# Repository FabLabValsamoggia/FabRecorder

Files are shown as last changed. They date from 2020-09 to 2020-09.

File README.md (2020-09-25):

# FabRecorder

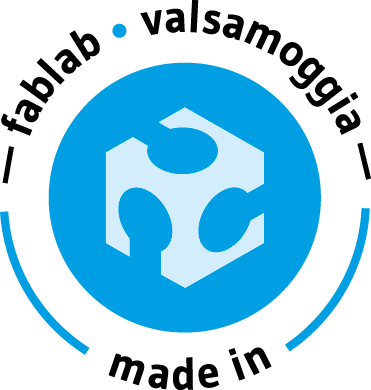
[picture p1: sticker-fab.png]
FabSticker


developed with ♥ by FabLab Valsamoggia

Based on [this awesome project](https://www.instructables.com/id/Make-Your-Own-Spy-Bug-Arduino-Voice-Recorder/).

**FabRecorder** is a little and adorable object, inspired by 007 gadget, that permits to record audio .wav format on SD card.

## Installation

Library requirements: [TMRpcm](https://github.com/TMRh20/TMRpcm). See code for other informations.

## Contributing

Pull requests are welcome. For major changes, please open an issue first to discuss what you would like to change.

Please make sure to update tests as appropriate.

## License

[MIT](https://choosealicense.com/licenses/mit/)

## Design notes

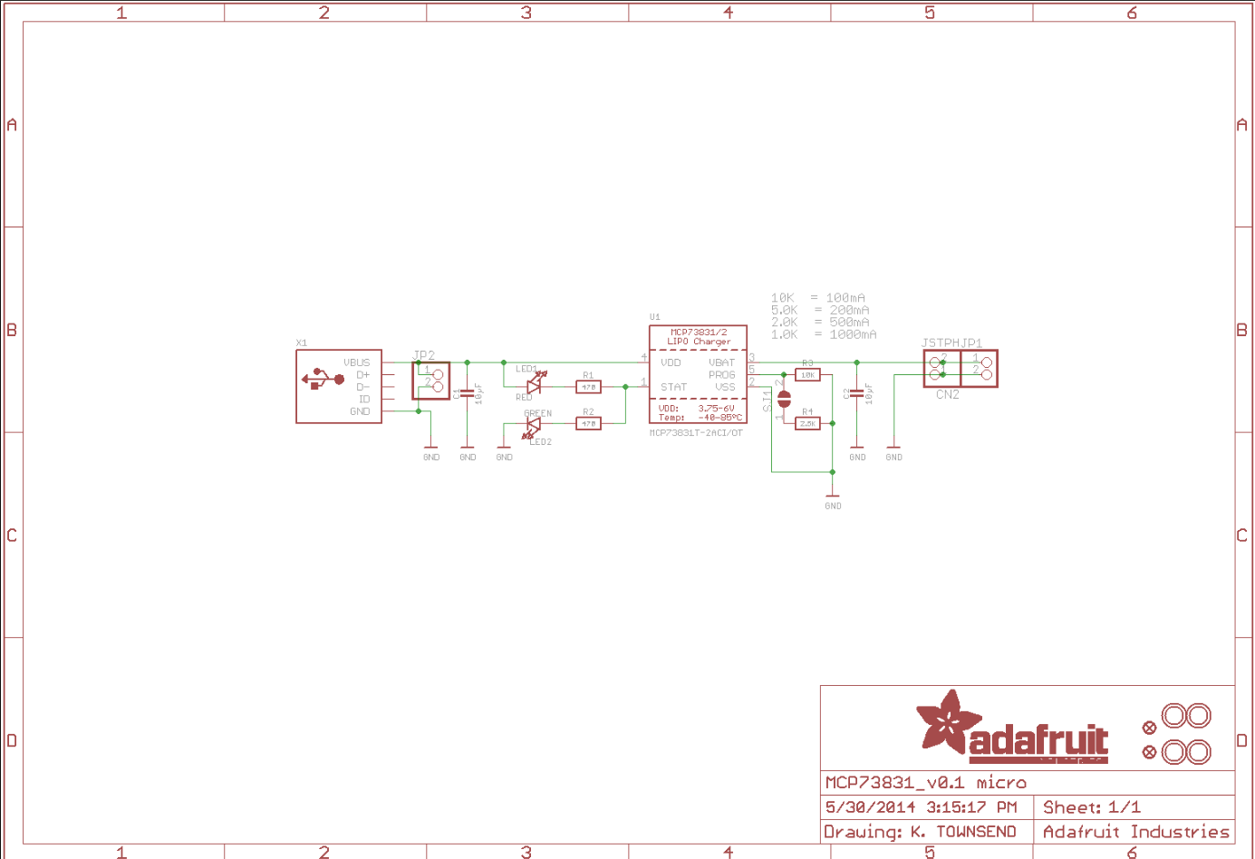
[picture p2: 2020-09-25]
doc/immagini/Annotazione 2020-04-22 233154.png

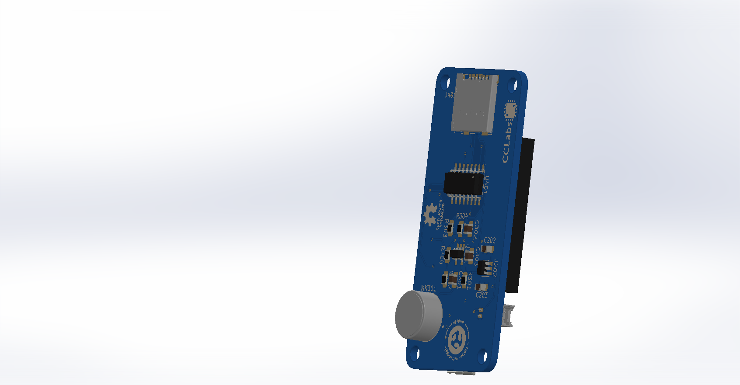
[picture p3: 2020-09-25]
doc/immagini/SPY_RECORDER-FBV010-Final2.PNG

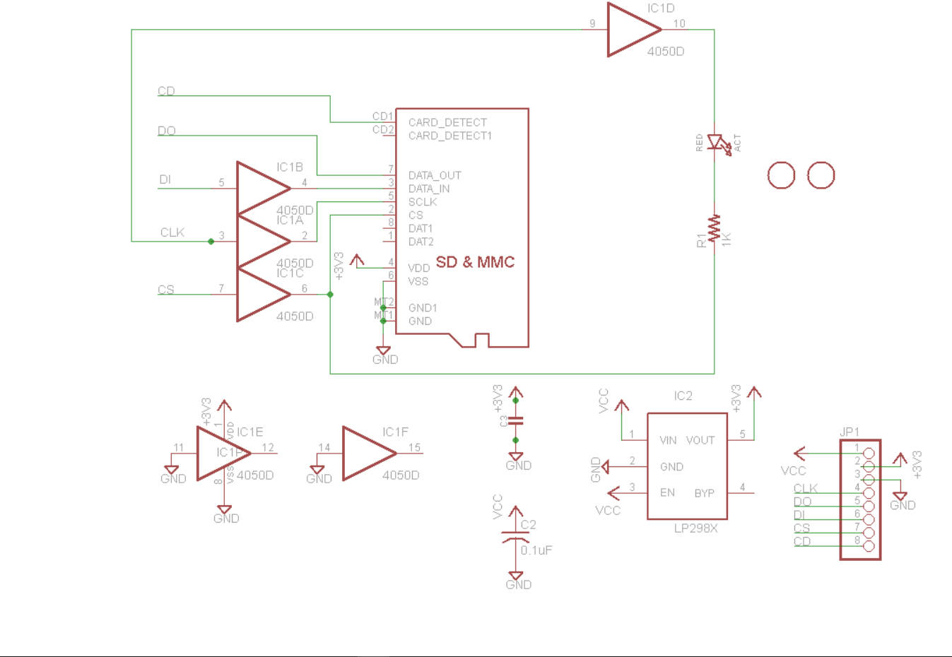
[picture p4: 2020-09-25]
doc/immagini/Annotazione 2020-04-22 232143.png

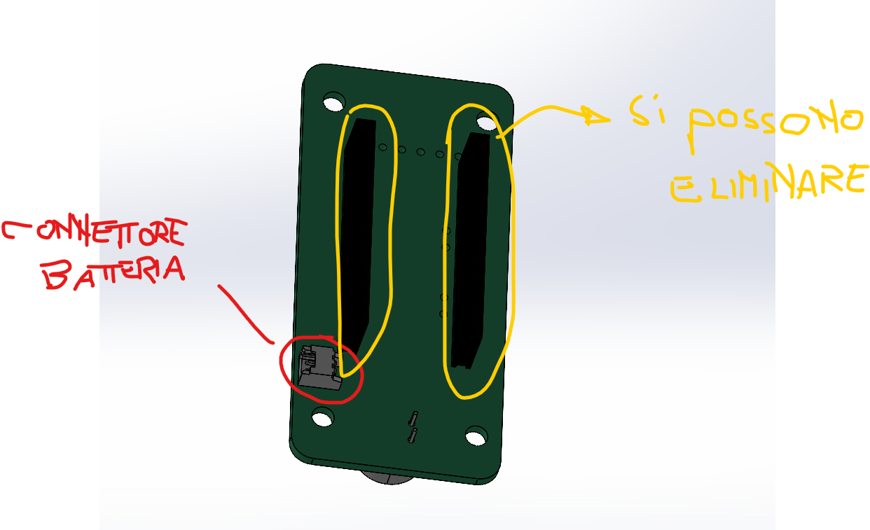
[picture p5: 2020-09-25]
doc/immagini/Annotazione 2020-04-23 194736.png

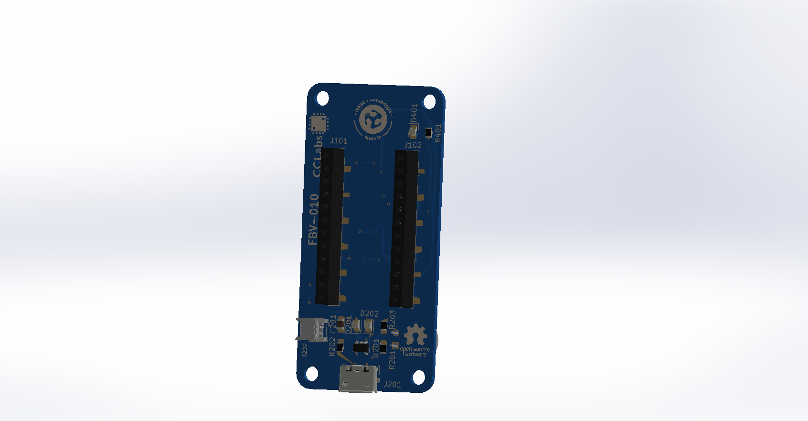
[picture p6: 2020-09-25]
doc/immagini/SPY_RECORDER-FBV010-Final1.PNG

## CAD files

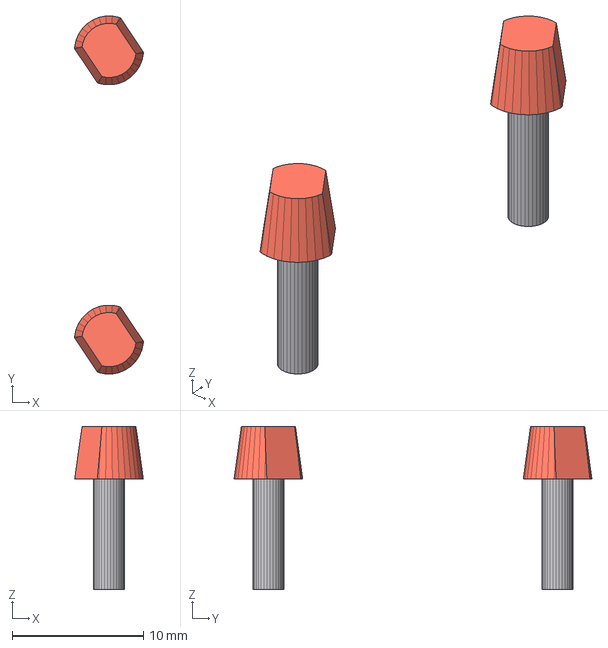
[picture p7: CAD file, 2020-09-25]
3D/Case/Fab-Recorder_PROTO-01/Fab-Recorder_PROTO-01_Fix.step
5.23 x 27.2 x 12.4 mm

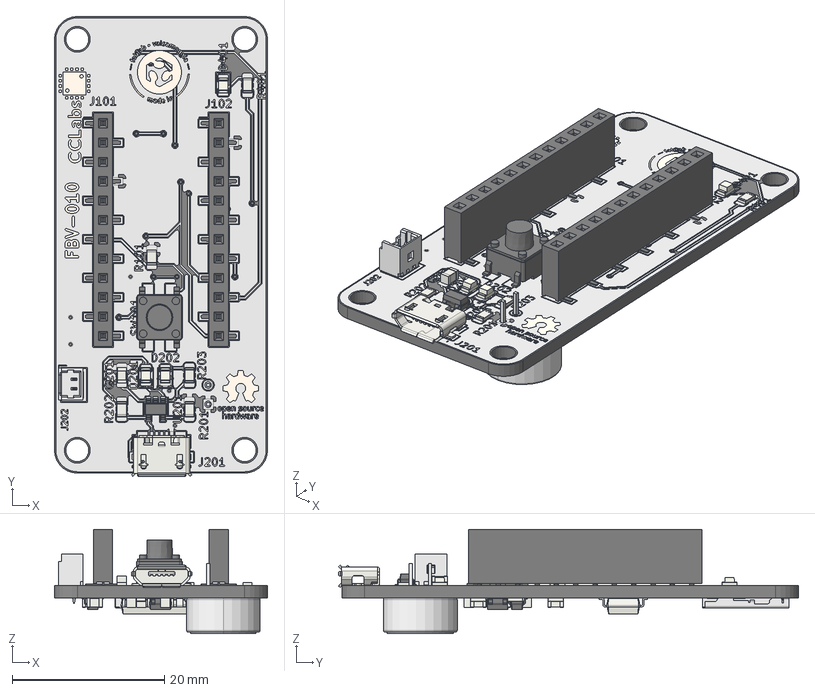
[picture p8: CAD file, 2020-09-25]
3D/Electronics/fab_recorder-v0.00.FCStd
28.0 x 60.4 x 13.7 mm
Pcb_d1c4
topTracks_d1c4
botTracks_d1c4
botSilks_e178
topSilks_20be
J202_1_5EAD8449
J102_PinSocket_1x12_P254mm_Vertical_SMD_Pin1Left_5EAD8A8B
J101_PinSocket_1x12_P254mm_Vertical_SMD_Pin1Left_5EAD8D9C
C201_C_0805_2012Metric_5EA27671
D201_LED_0805_2012Metric_5EA276D9
D202_LED_0805_2012Metric_5EA276EC
D401_LED_0805_2012Metric_5EA2E97C
J201_USB_Micro-B_Molex_47346-0001_5EA2771F
R201_R_0805_2012Metric_5EA27794
R202_R_0805_2012Metric_5EA277A5
R203_R_0805_2012Metric_5EA277B6
R401_R_0805_2012Metric_5EA2781C
U201_SOT_23_5_5EA27831
R101_R_0805_2012Metric_5EAC509F
SW101_button_smd_6x6xH_5EAC62BF
C202_C_0805_2012Metric_5EA27682
C203_C_0805_2012Metric_5EA27693
C301_C_0805_2012Metric_5EA276A4
C302_C_0805_2012Metric_5EAC5658
C303_C_0805_2012Metric_5EA276C6
J401_MicroSD-1040310811_5EAD7C73
MK301_CUI_DEVICES_CMA-4544PF-W_5EA2E783
R301_R_0805_2012Metric_5EA277C7
R302_R_0805_2012Metric_5EA277D8
R303_R_0805_2012Metric_5EA277E9
R304_R_0805_2012Metric_5EA277FA
R305_R_0805_2012Metric_5EA5CCE1
U202_SOT_23_5_5EA27846
U301_SOT_23_5_5EAC5485
U401_SOP_16_44x104mm_P127mm_5EA5B650

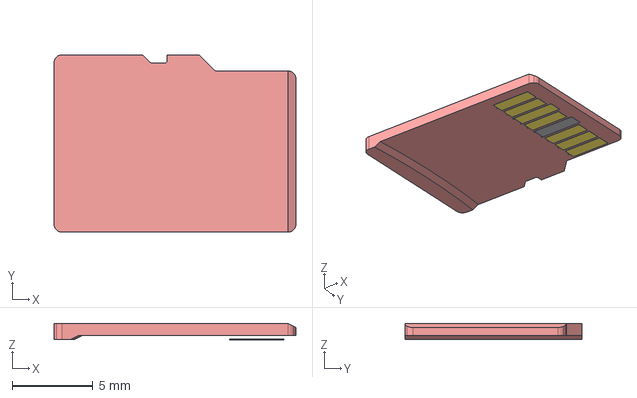
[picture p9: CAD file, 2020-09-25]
3D/Case/Fab-Recorder_PROTO-01/Fab-Recorder_PROTO-01_Micro SD.step
15.0 x 11.0 x 1.00 mm

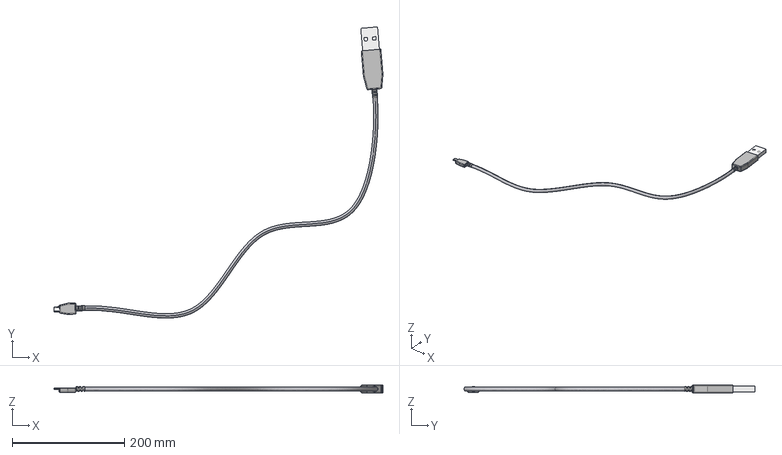
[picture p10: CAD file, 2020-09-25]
3D/Case/Fab-Recorder_PROTO-01/Fab-Recorder_PROTO-01_Cavo.step
585.0 x 517.8 x 15.0 mm

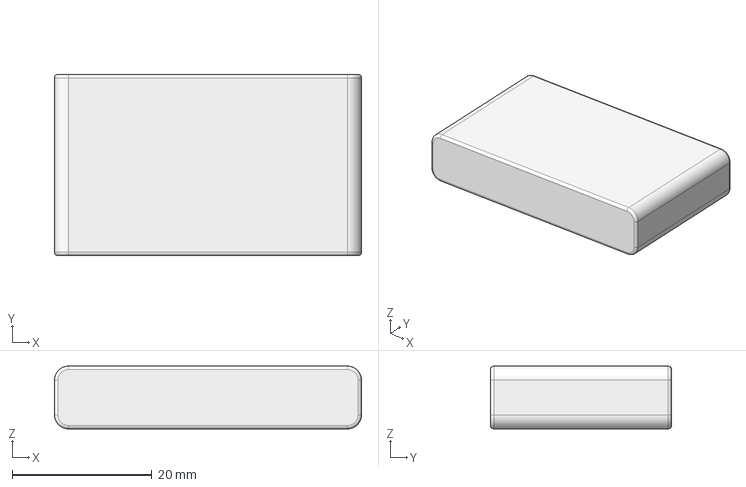
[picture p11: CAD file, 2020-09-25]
3D/Case/Fab-Recorder_PROTO-01/fab_recorder-v0.00.step
44.0 x 26.0 x 9.00 mm

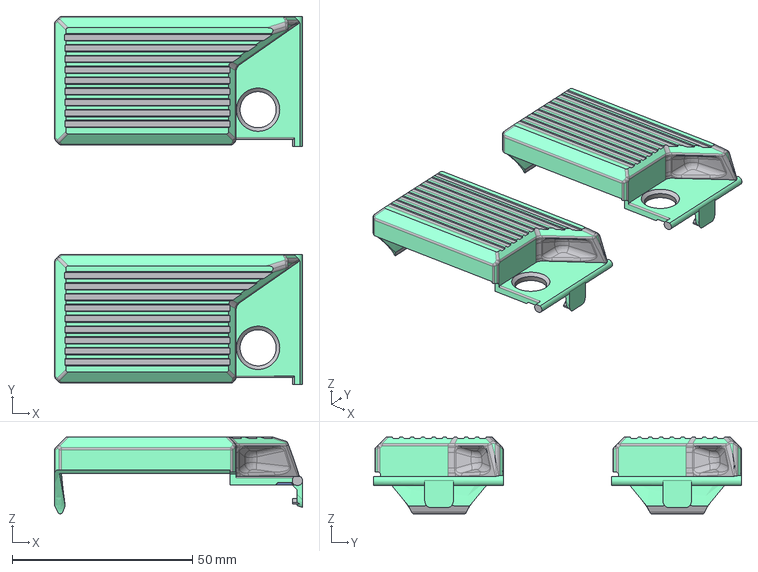
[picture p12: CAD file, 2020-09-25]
3D/Case/Fab-Recorder_PROTO-01/Fab-Recorder_PROTO-01_Capp.step
68.8 x 102.0 x 21.2 mm

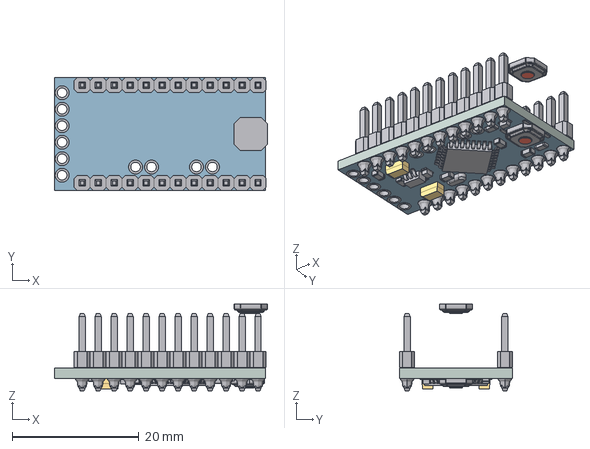
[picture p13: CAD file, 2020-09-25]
3D/Case/Fab-Recorder_PROTO-01/Fab-Recorder_PROTO-01_Imported 2.step
33.5 x 17.8 x 13.7 mm

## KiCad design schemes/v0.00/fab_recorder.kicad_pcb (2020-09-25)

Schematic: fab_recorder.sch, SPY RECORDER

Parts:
J101, J102: Conn_01x12_Female; PinSocket_1x12_P2.54mm_Vertical_SMD_Pin1Left
R101: 4K7; R_0805_2012Metric_Pad1.15x1.40mm_HandSolder
SW101: SW_Push; SW_SPST_TL3305A

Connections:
/0(Rx): J101.2
/1(Tx): J101.1
/2: J101.5
/3(**): J101.6
/4: J101.7, R101.1, SW101.2
/5(**): J101.8
/6(**): J101.9
/7: J101.10
/8: J101.11
/9(**): J101.12
/10(**/SS): J102.12; also elsewhere on the board
/11(**/MOSI): J102.11; also elsewhere on the board
/12(MISO): J102.10; also elsewhere on the board
/13(SCK): J102.9; also elsewhere on the board
/A0: J102.8; also elsewhere on the board
/A1: J102.7
/A2: J102.6
/A3: J102.5
/RAW: J102.1
/Reset: J101.3
/Reset2: J102.3
GND: J101.4, J102.2, R101.2; also elsewhere on the board
VCC: J102.4, SW101.1; also elsewhere on the board

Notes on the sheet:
Shield Arduino Pro Mini

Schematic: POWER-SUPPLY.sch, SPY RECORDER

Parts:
C201, C203: 10uF S; C_0805_2012Metric_Pad1.15x1.40mm_HandSolder
C202: 100nF S; C_0805_2012Metric_Pad1.15x1.40mm_HandSolder
D201: RED; LED_0805_2012Metric
D202: GREEN; LED_0805_2012Metric
J201: USB_B_Micro; USB_Micro-B_Molex_47346-0001
J202: Conn_01x02_Female; Molex_PicoBlade_53048-0210_1x02_P1.25mm_Horizontal
R201: 2K S; R_0805_2012Metric_Pad1.15x1.40mm_HandSolder
R202, R203: 470R S; R_0805_2012Metric_Pad1.15x1.40mm_HandSolder
U201: MCP73831-2-OT; SOT-23-5
U202: LP2981-33DBVT; SOT-23-5_HandSoldering; Mouser Part Number 595-LP2981-33DBVT

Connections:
/POWER SUPPLY/VBATT: C201.1, C202.1, J202.1, U201.3, U202.1 (VIN), U202.3 (ON/~OFF)
GND: C201.2, C202.2, C203.2, D202.1, J201.5, J202.2, R201.2, U201.2, U202.2 (GND); also elsewhere on the board
unnamed: D201.1, R203.2, U201.1
unnamed: D201.2, R202.2
unnamed: D202.2, R203.1
unnamed: J201.1, R202.1, U201.4
unnamed: R201.1, U201.5
VCC: C203.1, U202.5 (VOUT); also elsewhere on the board

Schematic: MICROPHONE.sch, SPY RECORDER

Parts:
C301, C302: 4.7uF S; C_0805_2012Metric_Pad1.15x1.40mm_HandSolder
C303: 100nF S; C_0805_2012Metric_Pad1.15x1.40mm_HandSolder
MK301: Microphone; MIC_CMA-4544PF-W
R301: 2.2K S; R_0805_2012Metric_Pad1.15x1.40mm_HandSolder
R302, R303, R304: 10K S; R_0805_2012Metric_Pad1.15x1.40mm_HandSolder
R305: 820K S; R_0805_2012Metric_Pad1.15x1.40mm_HandSolder
U301: OPA334; SOT-23-5_HandSoldering

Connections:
/A0: R305.1, U301.1; also elsewhere on the board
GND: C302.2, C303.2, MK301.1, R304.1, U301.2 (V-); also elsewhere on the board
unnamed: C301.1, R302.2
unnamed: C301.2, MK301.2, R301.2
unnamed: C302.1, R303.1, R304.2, U301.3 (+)
unnamed: R302.1, R305.2, U301.4 (-)
VCC: C303.1, R301.1, R303.2, U301.5 (V+); also elsewhere on the board

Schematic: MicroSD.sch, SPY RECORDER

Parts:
D401: RED; LED_0805_2012Metric
J401: Micro_SD_Card; microSD_HC_Molex_104031-0811
R401: 470; R_0805_2012Metric_Pad1.15x1.40mm_HandSolder
U401: CD74HC4050M; SOP-16_4.55x10.3mm_P1.27mm

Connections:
/10(**/SS): U401.7 (3A), U401.14 (6A); also elsewhere on the board
/11(**/MOSI): U401.5 (2A); also elsewhere on the board
/12(MISO): J401.7; also elsewhere on the board
/13(SCK): U401.3 (1A); also elsewhere on the board
GND: J401.6, U401.8 (GND); also elsewhere on the board
unnamed: D401.1, J401.2, U401.2 (1Y)
unnamed: D401.2, R401.2
unnamed: J401.3, U401.4 (2Y)
unnamed: J401.5, U401.6 (3Y)
unnamed: R401.1, U401.15 (6Y)
VCC: J401.4, U401.1 (VCC); also elsewhere on the board

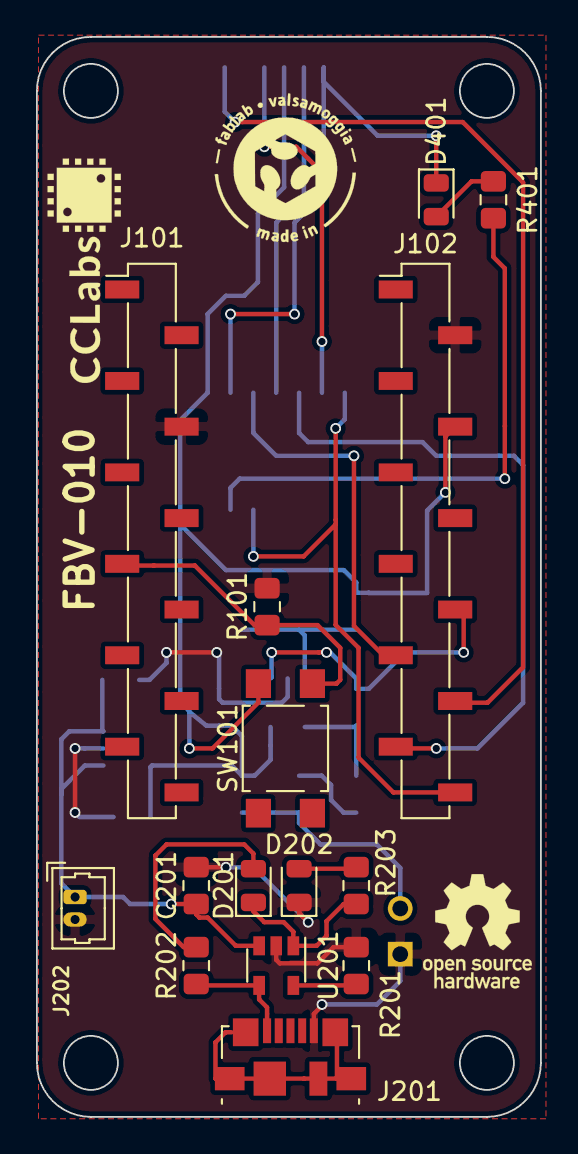
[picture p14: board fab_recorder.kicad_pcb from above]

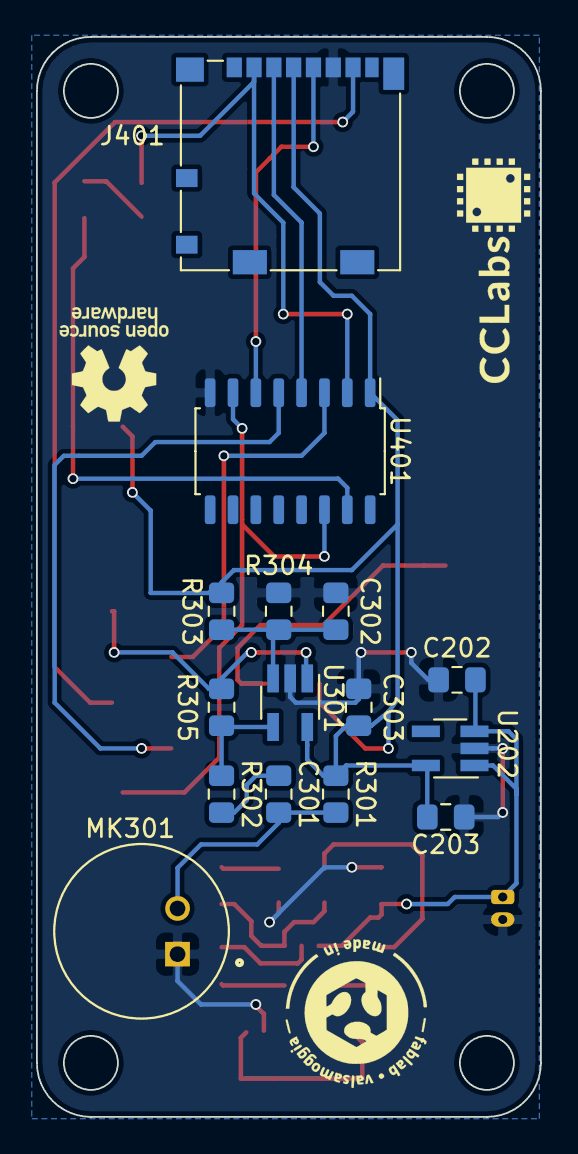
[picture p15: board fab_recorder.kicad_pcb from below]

Board: 2 copper layers, 28.0 x 60.0 mm, 30 parts (15 on the bottom side), 23 nets.

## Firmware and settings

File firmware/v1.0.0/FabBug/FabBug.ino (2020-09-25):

/*
Steps:
1. Edit pcmConfig.h
    a: On Uno or non-mega boards, #define buffSize 128. May need to increase.
    b: Uncomment #define ENABLE_RECORDING and #define BLOCK_COUNT 10000UL

2. Usage is as below. See https://github.com/TMRh20/TMRpcm/wiki/Advanced-Features#wiki-recording-audio for
   additional informaiton.
*/

#include <SD.h>
#include <SPI.h>
#include <TMRpcm.h>
#define SD_ChipSelectPin 10

TMRpcm audio;
int audiofile = 0;
unsigned long i = 0;
bool recmode = 0;

void setup() {
  pinMode(A0, INPUT);
  pinMode(6, OUTPUT);
  pinMode(2, INPUT_PULLUP);
  attachInterrupt(0, button, LOW);
  SD.begin(SD_ChipSelectPin);
  audio.CSPin = SD_ChipSelectPin;

}

void loop() {
}

void button() {
  while (i < 300000) {
    i++;
  }
  i = 0;
  if (recmode == 0) {
    recmode = 1;
    audiofile++;
    digitalWrite(6, HIGH);
    switch (audiofile) {
      case 1: audio.startRecording("1.wav", 16000, A0); break;
      case 2: audio.startRecording("2.wav", 16000, A0); break;
      case 3: audio.startRecording("3.wav", 16000, A0); break;
      case 4: audio.startRecording("4.wav", 16000, A0); break;
      case 5: audio.startRecording("5.wav", 16000, A0); break;
      case 6: audio.startRecording("6.wav", 16000, A0); break;
      case 7: audio.startRecording("7.wav", 16000, A0); break;
      case 8: audio.startRecording("8.wav", 16000, A0); break;
      case 9: audio.startRecording("9.wav", 16000, A0); break;
      case 10: audio.startRecording("10.wav", 16000, A0); break;
    }
  }
  else {
    recmode = 0;
    digitalWrite(6, LOW);
    switch (audiofile) {
      case 1: audio.stopRecording("1.wav"); break;
      case 2: audio.stopRecording("2.wav"); break;
      case 3: audio.stopRecording("3.wav"); break;
      case 4: audio.stopRecording("4.wav"); break;
      case 5: audio.stopRecording("5.wav"); break;
      case 6: audio.stopRecording("6.wav"); break;
      case 7: audio.stopRecording("7.wav"); break;
      case 8: audio.stopRecording("8.wav"); break;
      case 9: audio.stopRecording("9.wav"); break;
      case 10: audio.stopRecording("10.wav"); break;
    }
  }
}
